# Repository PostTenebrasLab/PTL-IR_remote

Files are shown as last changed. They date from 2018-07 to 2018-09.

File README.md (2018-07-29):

# PTL IR remote

PTL IR remote is a wemos shield with sensors and actuators.

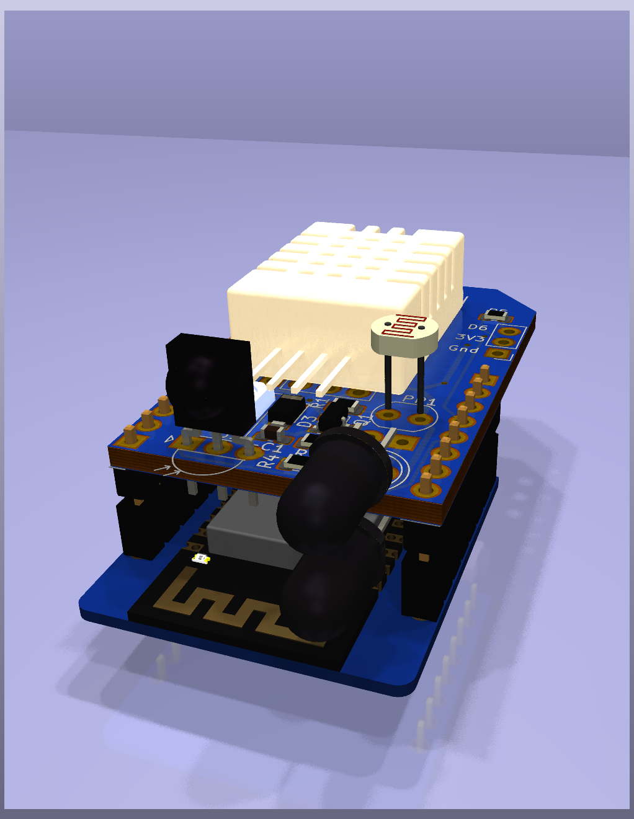
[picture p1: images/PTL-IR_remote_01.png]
Logo Title Text 1


## Sensors / Actuators

 * IR leds
 * IR receiver
 * DHT22 temperature/humidity
 * brithness (photoresistor)
 * optional ds18b20 termometer (or any OneWire perif)
 * optional bme280 temperature/humidity/pressure

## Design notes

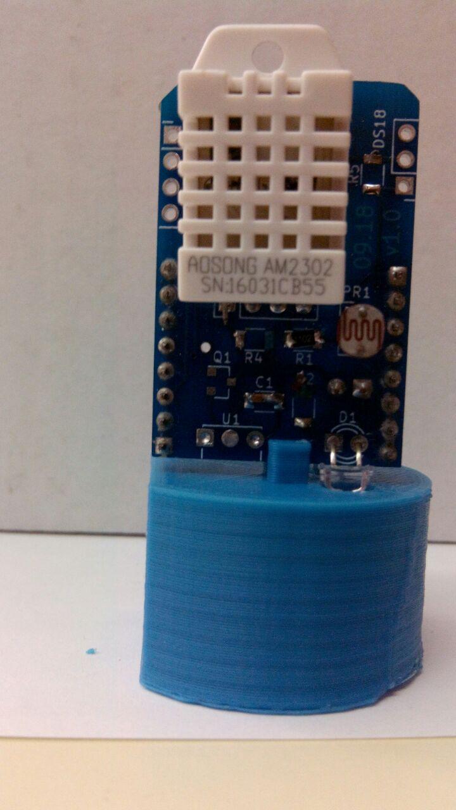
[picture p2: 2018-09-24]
presentation_workshop/pics/led_support.jpg

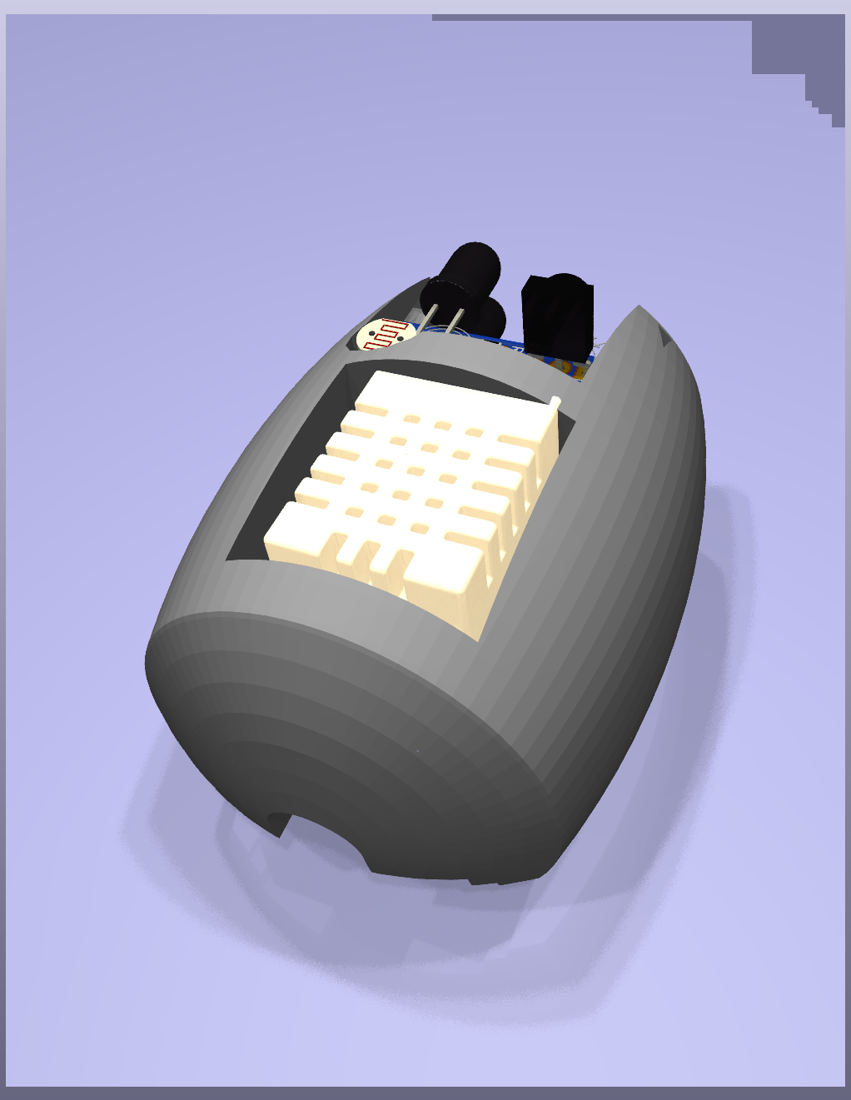
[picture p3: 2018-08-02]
presentation_workshop/images/PTL-IR_remote_case_02.png

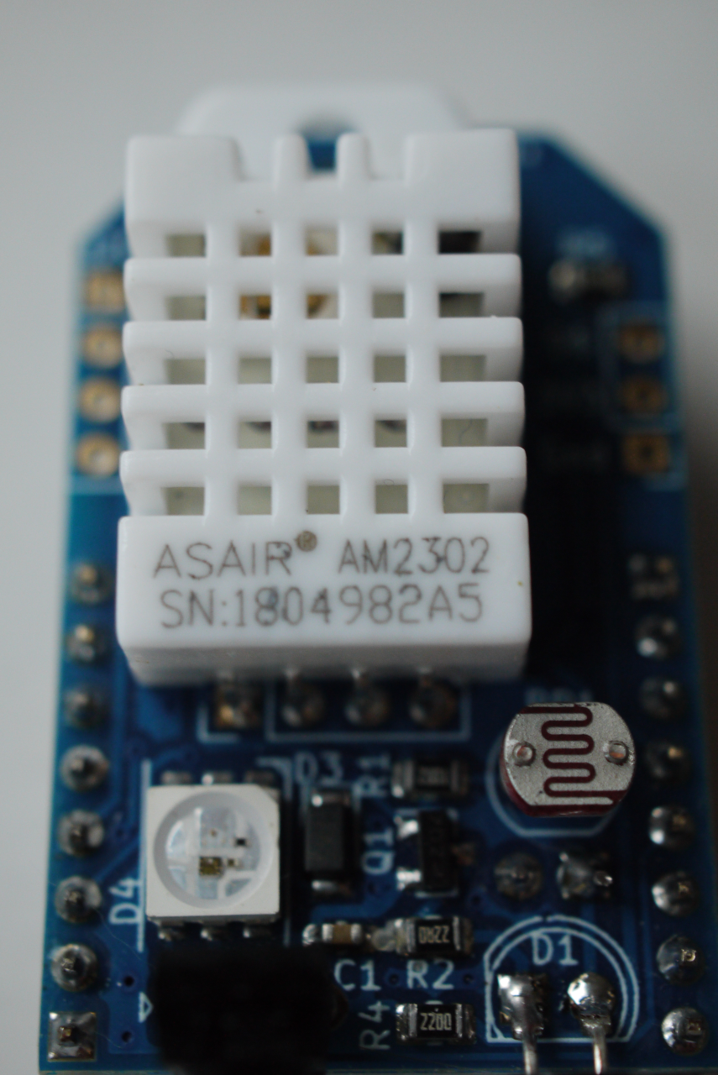
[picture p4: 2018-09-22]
presentation_workshop/pics/DHT22_1.png

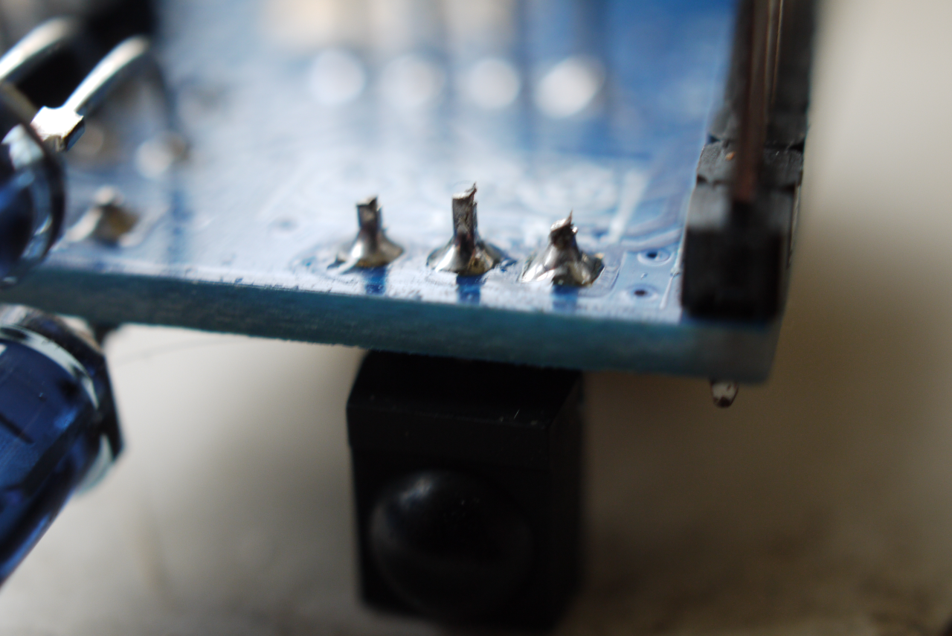
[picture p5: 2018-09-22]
presentation_workshop/pics/exemple_receiver.png

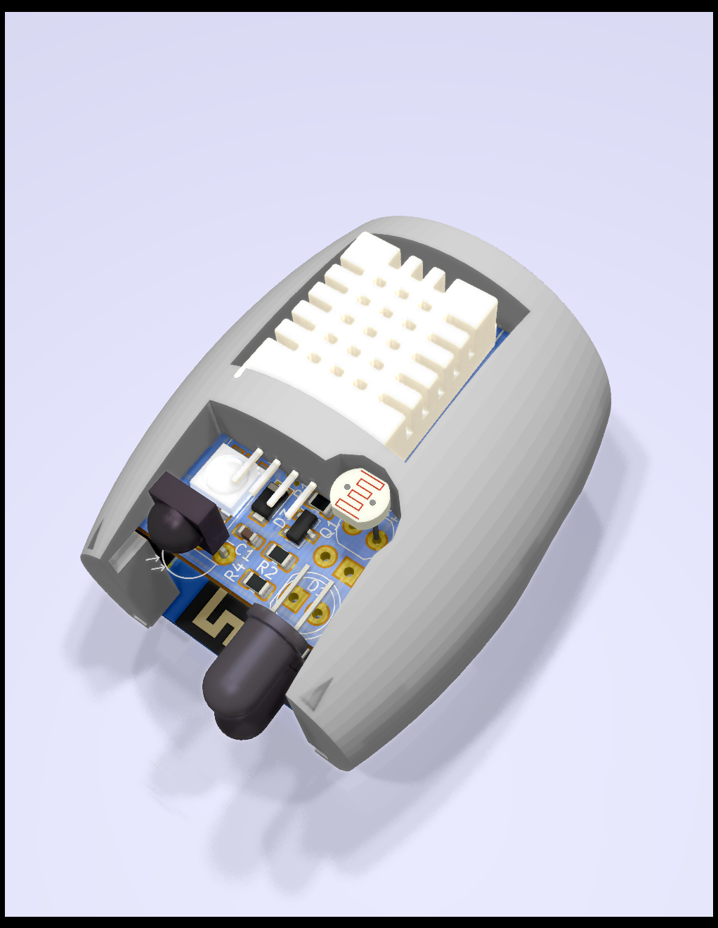
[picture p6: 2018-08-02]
presentation_workshop/images/PTL-IR_remote_case_04.png

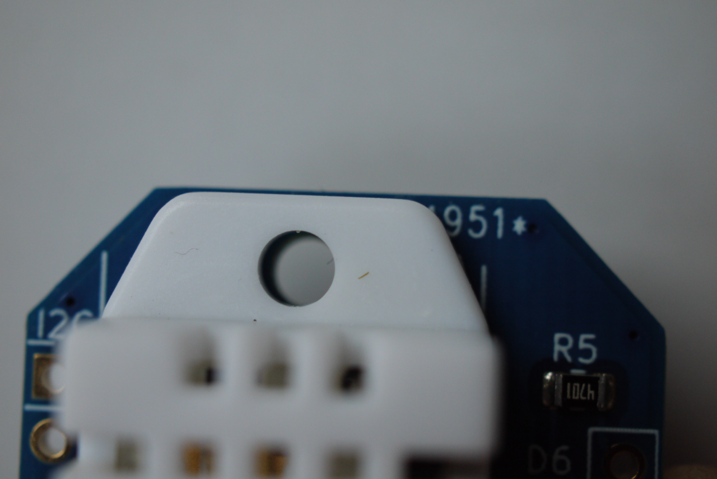
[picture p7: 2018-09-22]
presentation_workshop/pics/DHT22_2.png

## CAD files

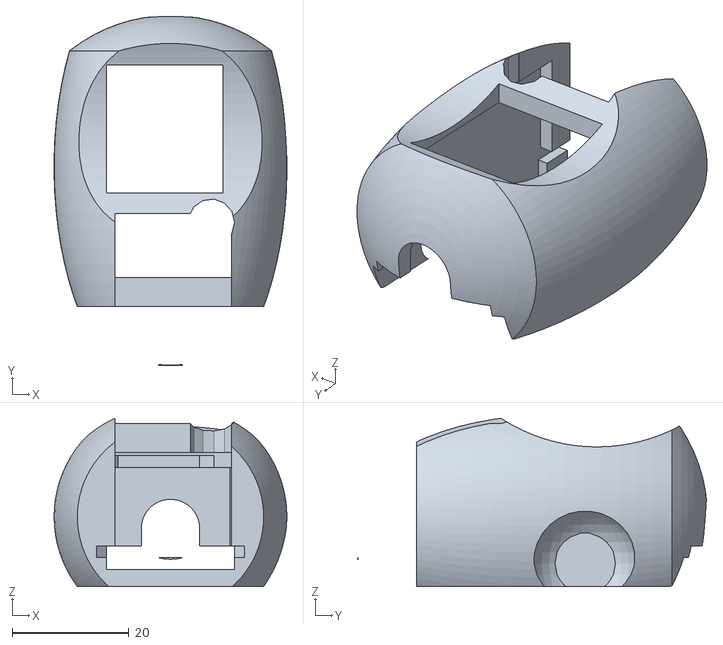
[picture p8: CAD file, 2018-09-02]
mechanical/PTL_IR_remote_case.stl
40.0 x 59.9 x 28.9

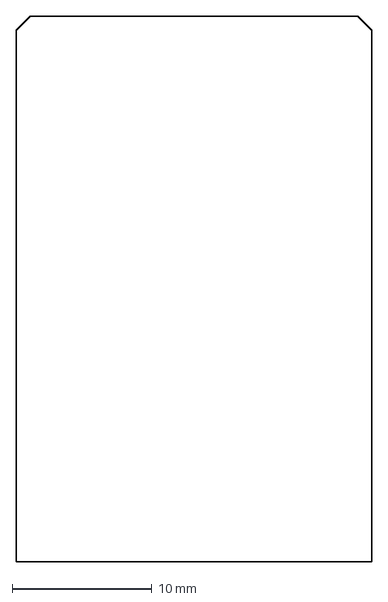
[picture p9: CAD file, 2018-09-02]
mechanical/shield_space.dxf
25.4 x 39.0 mm

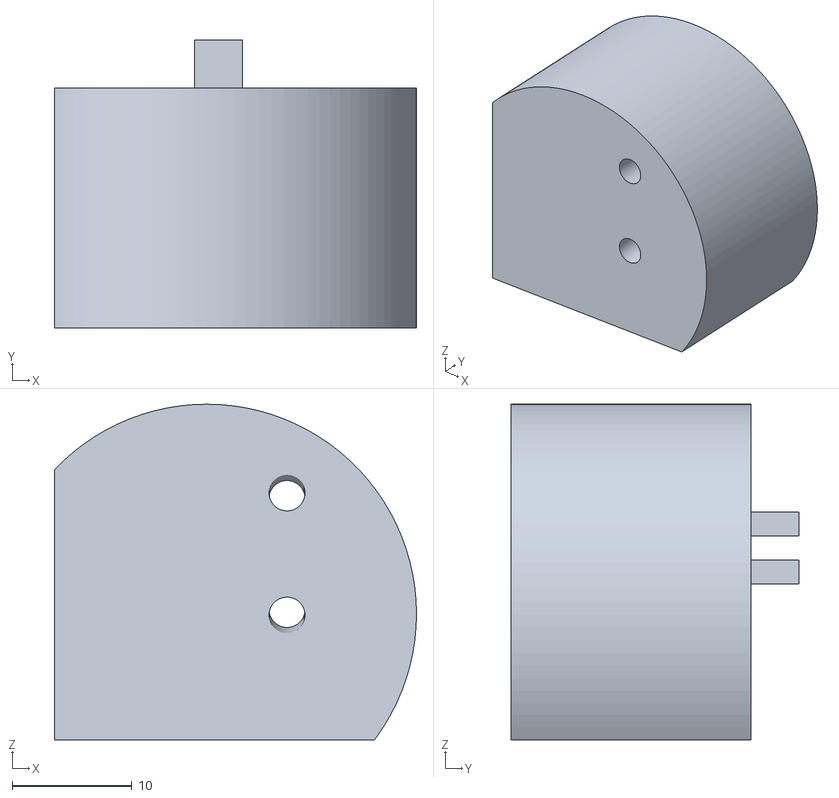
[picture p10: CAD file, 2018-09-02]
mechanical/soldering_support.stl
30.2 x 24.0 x 28.0

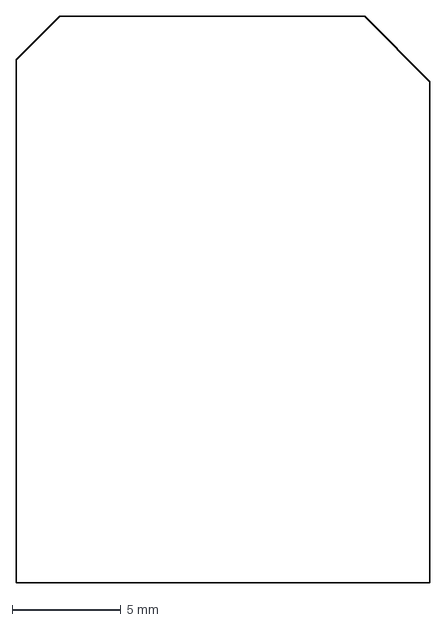
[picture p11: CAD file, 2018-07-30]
mechanical/dht.dxf
19.0 x 26.0 mm

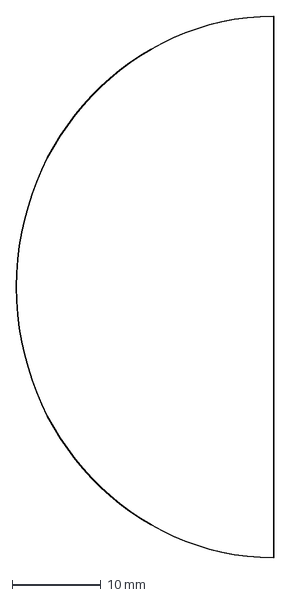
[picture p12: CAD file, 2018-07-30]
mechanical/ovoid.dxf
29.0 x 61.0 mm

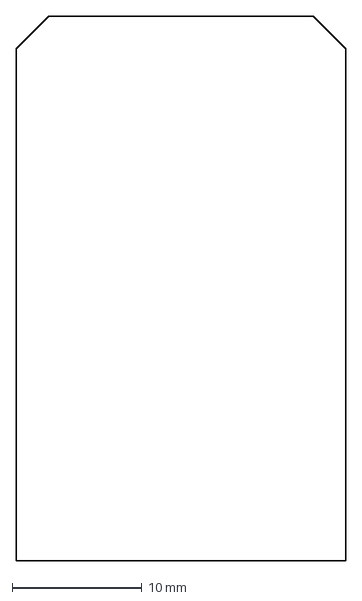
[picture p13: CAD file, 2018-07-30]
mechanical/shield.dxf
25.4 x 42.0 mm

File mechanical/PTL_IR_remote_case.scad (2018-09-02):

/* =====================================================================================
 *
 *       Filename:  sPTL_ir_remote_case.scad
 *
 *    Description:  PTL IR remote control case for LemanMake 2018 PTL workshop
 *
 *        Version:  1.0
 *        Created:  02 09 2018
 *       Revision:  none
 *       Compiler:  gcc
 *
 *         Author:  Sebastien Chassot (sinux), sinux@posttenebraslab.ch.ch
 *        Company:  Post Tenebras Lab (Geneva's Hackerspace)
 *
 * =====================================================================================
 */


case();
//esp();
//esp_clearance();

module case (){
color([0,1,0])
difference(){
    case_full();
    esp_clearance();
}
}

/**
 *    Case without clearance
 **/
module case_full () {

    difference(){
        translate([0,-16,5])
        rotate([-90,0,0])
        intersection(){
    
            rotate_extrude(convexity = 10, $fn=80)import(file = "ovoid.dxf");
    
            translate([0,0,35])
                scale([1,1,2])sphere(d=40, $fn=80);
        }
        translate([-50,-50,-27])
            cube([100,100,20]);
        
        //truncate
        translate([-20,-15,-20])
            cube([40,10,40]);
        
        translate([0, 26, 47])
        rotate([0, 90, 0])
            cylinder(d=60, h=100, center=true, $fn=100);
    }
}


/**
 *    wemos + shield
 **/
module esp () {
    
    union() {
        // wemos
        color([0,0,1])
        translate([-25.4/2,-7,-2])
            cube([25.4,35,2]);
        
        // headers
        color([0,0,0])
        translate([-25.4/2,0,0])
            cube([2.54,23,11.5]);
        color([0,0,0])
        translate([25.4/2-2.54,0,0])
            cube([2.54,23,11.5]);
        
        // shield
        color([0,0,1])
        translate([0,0,11.5])
            linear_extrude(2)import(file = "shield.dxf");
        
        // DHT
        translate([-9.5,15,7.5]){
            color([1,1,1])
            translate([-1,0,6])
                cube([19,20,7.5]);
            
            color([1,1,1])
            translate([-1,.5,6])
                linear_extrude(2)import(file = "dht.dxf");
        }
    }
}

/**
 *    wemos clearance
 **/
module esp_clearance () {
    color([1,0,0])
    union() {
         // shield
        translate([0, 0, -2])
            linear_extrude(15.5)import(file = "shield.dxf");
        
        translate([-25.4/2, -30, -2])
            cube([25.4, 60, 2]);
        
        // shield space
        translate([0, -3, 13.5])
            linear_extrude(2.5)import(file = "shield_space.dxf");
            
        // DHT
        translate([-10,14.5,13.5]){
            color([1,1,1])
            translate([-1,0,0])
                cube([20,22,14]);
            
            color([1,1,1])
            translate([-1,.5,0])
                linear_extrude(2)import(file = "dht.dxf");
        };
    
    
        // clear space
        translate([-9.5,-17,-2]) 
            cube([20,28,27]);
        
        // clip
        translate([-11,-15,-4]) 
            cube([22,70,4]);
        translate([-25.4/2,0,-7])
            cube([25.4,45,5]);
    
        // USB wire
        translate([0,47,3])
        rotate([90,0,0]) {
            cylinder(d=10, h=10, $fn=100);
            translate([0, -4, 5])
                cube([10, 8, 10],center=true);
        }

        // photoresistor
        translate([7,9.5,0])
            cylinder(d=8, h=40);
        
        
        // reset button
        translate([20,24,-3])
            sphere(d=18);
    }
}

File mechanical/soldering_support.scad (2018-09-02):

/* =====================================================================================
 *
 *       Filename:  soldering_support.scad
 *
 *    Description:  Soldering support for LemanMake 2018 PTL workshop
 *
 *        Version:  1.0
 *        Created:  02 09 2018
 *       Revision:  none
 *       Compiler:  gcc
 *
 *         Author:  Sebastien Chassot (sinux), sinux@posttenebraslab.ch.ch
 *        Company:  Post Tenebras Lab (Geneva's Hackerspace)
 *
 * =====================================================================================
 */

LEDS_ANGLE=3;

support();

module support() {
    union() {
        difference() {    
            translate([0, 0, 35/2-7])
                rotate([90, 0, 0])
                    cylinder(d=35, h=20, $fn=100);

            union() {
                translate([6.7, 1, 11.5])
                    rotate([90+LEDS_ANGLE, 0, 0]) {
                        cylinder(d1=5.7, d2=4.7, h=12, $fn=100);
                        cylinder(d=3, h=22, $fn=100);
                    };

                translate([6.7, 1, 19.5])
                    rotate([90-LEDS_ANGLE, 0, 0]) {
                        cylinder(d1=5.7, d2=4.7, h=12, $fn=100);
                        cylinder(d=3, h=22, $fn=100);
                    };

                translate([0, 0, -15])
                    cube([50, 50, 30], center=true);
                cube([26.5, 15, 4], center=true);
                
                rotate([0, 90, 0]) {
                    translate([0, 0, -27.7]) {
                        cube([50, 50, 30], center=true);
                    }
                    
                }
               // cube([26.5, 15, 4], center=true);
            }
        }

        translate([0, 0, 16])
            rotate([0, 90, 0]) {
                translate([-3, -1, -1])
                    cube([2, 5, 4]);
                translate([1, -1, -1])
                    cube([2, 5, 4]);
            }
    }
}

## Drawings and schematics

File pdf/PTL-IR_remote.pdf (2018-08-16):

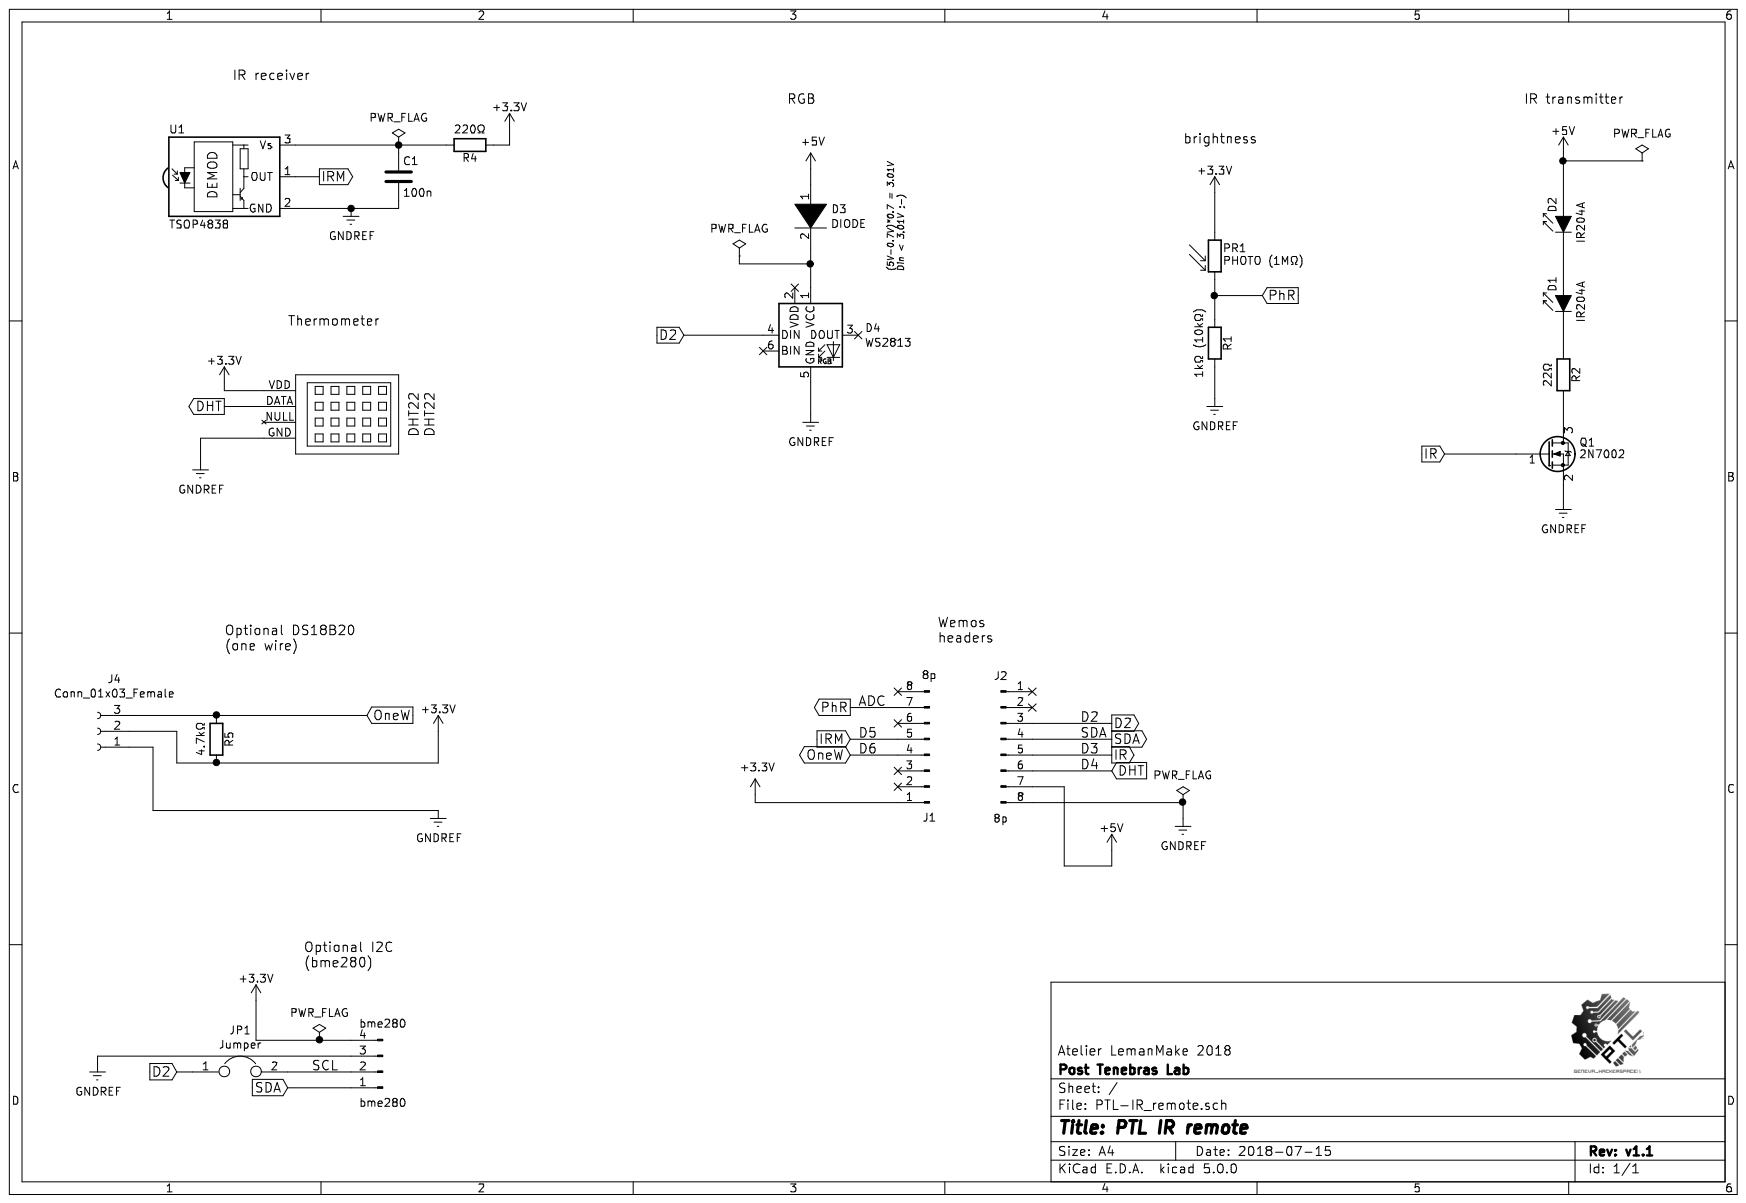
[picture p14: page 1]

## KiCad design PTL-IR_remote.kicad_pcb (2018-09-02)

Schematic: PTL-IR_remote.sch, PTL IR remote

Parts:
C1: 100n; C_0603_1608Metric_Pad1.05x0.95mm_HandSolder
D1, D2: IR204A; LED_D5.0mm_IRGrey
D3: DIODE; D_PowerDI-123
D4: WS2813; LED_WS2812_PLCC6_5.0x5.0mm_P1.6mm
DHT22: DHT22; PinHeader_1x04_P2.54mm_Vertical
J1, J2: 8p; PinHeader_1x08_P2.54mm_Vertical
J4: Conn_01x03_Female; PinHeader_1x03_P2.54mm_Vertical
JP1: Jumper; solder-jumper-2
PR1: PHOTO (1MΩ); R_LDR_4.9x4.2mm_P2.54mm_Vertical
Q1: 2N7002; SOT-23
R1: 1kΩ (10kΩ); R_0805_2012Metric
R2: 22Ω; R_0805_2012Metric
R4: 220Ω; R_0805_2012Metric
R5: 4.7kΩ; R_0805_2012Metric
U1: TSOP4838; Vishay_MINIMOLD-3Pin
bme280: bme280; PinHeader_1x04_P2.54mm_Vertical

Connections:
+3V3: DHT22.1, J1.1, J4.2, PR1.1, R4.1, R5.2, bme280.4
+5V: D2.2 (A), D3.1, J2.8
DHT: DHT22.2, J2.3, JP1.1
GNDREF: C1.2, D4.5, DHT22.4, J2.7, J4.1, Q1.2 (S), R1.2, U1.2 (GND), bme280.3
IR: J2.5, Q1.1 (G)
IRM: J1.5, U1.1 (OUT)
unnamed: C1.1, R4.2, U1.3 (Vs)
unnamed: D1.1 (K), R2.1
unnamed: D1.2 (A), D2.1 (K)
unnamed: D3.2, D4.1
unnamed: JP1.2, bme280.2
unnamed: Q1.3 (D), R2.2
OneW: J1.4, J4.3, R5.1
PhR: J1.7, PR1.2, R1.1
RGB: D4.4, J2.6
SDA: J2.4, bme280.1

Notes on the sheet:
(5V-0.7V)*0.7 = 3.01V Din < 3.01V ;-)
Optional DS18B20 (one wire)
Optional I2C (bme280)
IR receiver
Thermometer
Wemos headers
RGB
brightness
IR transmitter
SCL

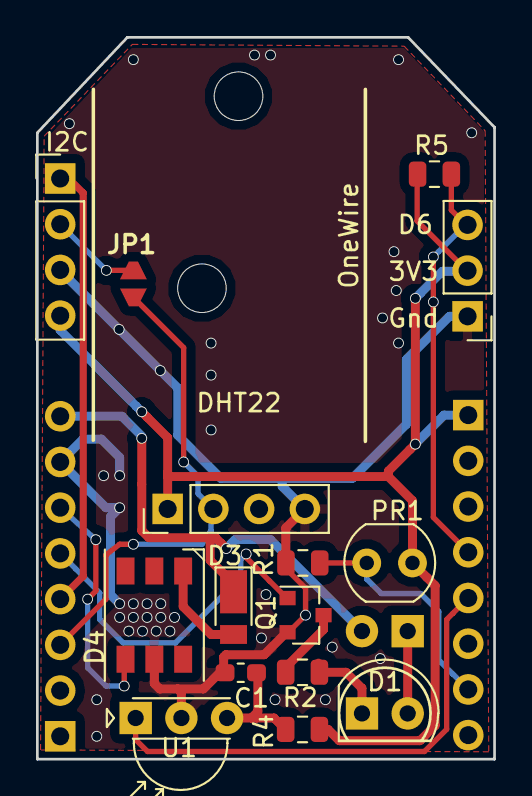
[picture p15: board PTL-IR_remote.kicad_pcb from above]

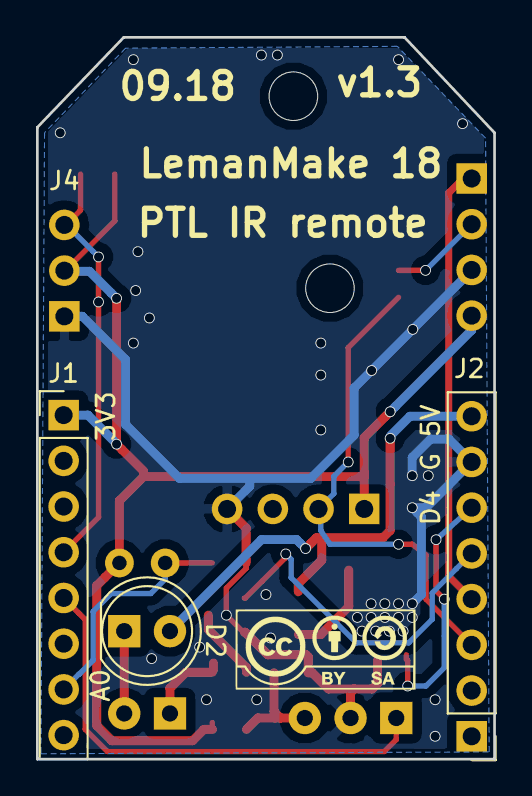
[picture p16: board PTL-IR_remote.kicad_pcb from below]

Board: 2 copper layers, 25.4 x 40.1 mm, 18 parts (3 on the bottom side), 16 nets.

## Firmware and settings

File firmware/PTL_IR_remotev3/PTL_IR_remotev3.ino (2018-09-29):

/*
  WS2812FX Webinterface.
  
  Harm Aldick - 2016
  www.aldick.org

  
  FEATURES
    * Webinterface with mode, color, speed and brightness selectors


  LICENSE

  The MIT License (MIT)

  Copyright (c) 2016  Harm Aldick 

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
  
  CHANGELOG
  2016-11-26 initial version
  2018-01-06 added custom effects list option and auto-cycle feature
  
*/

#include <WiFiManager.h>
#include <DNSServer.h>
#include <ESP8266mDNS.h>

#include <ESP8266WebServer.h>
#include <ESP8266OTA.h>
#include <ESP8266httpUpdate.h>

#include <DHTesp.h>
#include <WS2812FX.h>

#include <IRremoteESP8266.h>
#include <IRrecv.h>
#include <IRsend.h>
#include <IRutils.h>
#include <ir_Daikin.h>
#include <ir_Fujitsu.h>
#include <ir_Gree.h>
#include <ir_Haier.h>
#include <ir_Kelvinator.h>
#include <ir_Midea.h>
#include <ir_Toshiba.h>

#include "PTL_IR_remotev3.h"

extern const char index_html[];
extern const char ws2813_html[];
extern const char ir_html[];

extern const char main_js[];
extern const char ir_js[];
extern const char ws2813_js[];

#define WIFI_TIMEOUT 30000              // checks WiFi every ...ms. Reset after this time, if WiFi cannot reconnect.
#define HTTP_PORT 80

#define CAPTURE_BUFFER_SIZE 1024
#define TIMEOUT 15U  // Suits most messages, while not swallowing many repeats.
#define MIN_UNKNOWN_SIZE 12
#define DEFAULT_COLOR 0x00FF00
#define DEFAULT_BRIGHTNESS 255  // 0..255
#define DEFAULT_SPEED 1000
#define DEFAULT_MODE FX_MODE_BREATH


//#define DEBUG


unsigned long auto_last_change = 0;
unsigned long last_wifi_check_time = 0;
String modes = "";
uint8_t myModes[] = {}; // *** optionally create a custom list of effect/mode numbers
boolean auto_cycle = false;
int8_t brightness = DEFAULT_BRIGHTNESS;
uint8_t lastMode;

/*****  WIFI  *****/
WiFiManager wifiManager;
ESP8266WebServer server(HTTP_PORT);
ESP8266OTA otaUpdater;

/*****  IR  *****/
IRsend irsend = IRsend(IR_LED_PIN);
IRrecv irrecv(IR_RECV_PIN, 1024, 15u, true);
decode_results results;  // Somewhere to store the results
bool ir_lock = false;  // Primitive locking for gating the IR LED.
uint16_t * newCodeArray(const uint16_t size);
uint16_t countValuesInStr(const String str, char sep);
uint32_t sendReqCounter = 0;
// HTML arguments we will parse for IR code information.
#define argType "type"
#define argData "code"
#define argBits "bits"
#define argRepeat "repeats"

/*****  DHT and LED  *****/
DHTesp dht;
WS2812FX ws2812fx = WS2812FX(LED_COUNT, LED_PIN, NEO_GRB + NEO_KHZ800);
long timer_serial = 0;


// QUICKFIX...See https://github.com/esp8266/Arduino/issues/263
#define min(a,b) ((a)<(b)?(a):(b))
#define max(a,b) ((a)>(b)?(a):(b))

/**
 * 
 */
void wifi_setup() {
    delay(10);

    // We start by connecting to a WiFi network
    wifiManager.setTimeout(300);  // Time out after 5 mins.
    if (!wifiManager.autoConnect(WIFI_AP_NAME)) {
        Serial.print("Wifi failed to connect and hit timeout.");
        // Reboot. A.k.a. "Have you tried turning it Off and On again?"
        ESP.reset();
    }
    if (!MDNS.begin(HOSTNAME)) {
        Serial.println("Error setting up MDNS responder!");
    }
    Serial.print("WiFi connected. IP address:\t");
    Serial.println(WiFi.localIP().toString());
    Serial.print("WiFi connected. MAC address:\t");
    Serial.println(WiFi.macAddress());
}

/**
 * 
 */
bool updateOTA(){

    t_httpUpdate_return  ret = ESPhttpUpdate.update(FW_UPDATE_URL);

//    Serial.println(ESPhttpUpdate.getLastError());
    switch(ESPhttpUpdate.getLastError()) {
        case 11:
            Serial.println("OTA : Updating firmware...");
            break;
        case -11:
            Serial.println("OTA : esp unknown in PTL esp DB...");
            break;
        case -1:
            Serial.println("OTA : No server found");
            break;
        case -102:
            Serial.println("OTA : No update needed current firmware is up to date.");
            break;
        default:
           Serial.println("Unknown error");
    }
    return (ret == 11) ? true : false;    
}

void calibrateIr(int8_t* offset){

  irsend.begin();

  *offset = irsend.calibrate();

}


void irInit(){
  irsend.begin();
  irrecv.setUnknownThreshold(MIN_UNKNOWN_SIZE);
  irrecv.enableIRIn();  // Start the receiver
}


void readIr(){
   // Check if the IR code has been received.
  if (irrecv.decode(&results)) {
    
    translateIR();

    if (results.overflow)
      Serial.printf("WARNING: IR code is too big for buffer (>= %d). "
                    "This result shouldn't be trusted until this is resolved. "
                    "Edit & increase CAPTURE_BUFFER_SIZE.\n",
                    CAPTURE_BUFFER_SIZE);
#ifdef DEBUG
    Serial.print(resultToHumanReadableBasic(&results));
#endif
    yield();  // Feed the WDT (again)

  }
}

void translateIR() // takes action based on IR code received

// describing Car MP3 IR codes 

{

  switch(results.value)

  {

  case 0xFF00FF:  
    Serial.println(" On             ");
    ws2812fx.setMode(lastMode);
    ws2812fx.setBrightness(brightness);
    break;

  case 0xFF807F:  
    Serial.println(" Off            ");
    lastMode = ws2812fx.getMode();
    ws2812fx.setBrightness(0);
    break;

  case 0xFF40BF:  
    Serial.println(" Flash          ");
    (ws2812fx.getMode() == 34) ? ws2812fx.setMode(0) : ws2812fx.setMode(34);
    break;

  case 0xFF20DF:  
    Serial.println(" Strobe         ");
    (ws2812fx.getMode() == 34) ? ws2812fx.setMode(0) : ws2812fx.setMode(34);
    break;

  case 0xFFA05F:  
    Serial.println(" Fade           ");
    (ws2812fx.getMode() == 15) ? ws2812fx.setMode(0) : ws2812fx.setMode(15);
    break;

  case 0xFF609F:  
    Serial.println(" Smooth         "); 
    (ws2812fx.getMode() == 15) ? ws2812fx.setMode(0) : ws2812fx.setMode(15);
    break;

  case 0xFF10EF:  
    Serial.println(" Light Up       ");
    brightness = (brightness >= 230) ? 255 : brightness + 25;
    ws2812fx.setBrightness(brightness);
    break;

  case 0xFF906F:  
    Serial.println(" Light Down     ");
    brightness = (brightness <= 25) ? 0 : brightness - 25;
    ws2812fx.setBrightness(brightness);
    break;

  case 0xFF50AF:  
    Serial.println(" W              ");
    ws2812fx.setColor(WHITE);
    break;

  case 0xFF30CF:  
    Serial.println(" Red            "); 
    ws2812fx.setColor(RED);
    break;

  case 0xFFB04F:  
    Serial.println(" Green          "); 
    ws2812fx.setColor(GREEN);
    break;

  case 0xFF708F:  
    Serial.println(" Blue           "); 
    ws2812fx.setColor(BLUE);
    break;

  case 0xFF08F7:  
    Serial.println(" c1             "); 
    ws2812fx.setColor(ORANGE);
    break;

  case 0xFF8877:  
    Serial.println(" c2             "); 
    ws2812fx.setColor(GREEN);
    break;

  case 0xFF48B7:  
    Serial.println(" c3             "); 
    ws2812fx.setColor(BLUE);
    break;

  case 0xFF28D7:  
    Serial.println(" c4             "); 
    ws2812fx.setColor(GREEN);
    break;

  case 0xFFA857:
    Serial.println(" c5             "); 
    ws2812fx.setColor(CYAN);
    break;

  case 0xFF6897:  
    Serial.println(" c6             "); 
    ws2812fx.setColor(PINK);
    break;

  case 0xFF18E7:  
    Serial.println(" c7             "); 
    ws2812fx.setColor(YELLOW);
    break;

  case 0xFF9867:  
    Serial.println(" c8             "); 
    ws2812fx.setColor(GREEN);
    break;

  case 0xFF58A7:  
    Serial.println(" c9             "); 
    ws2812fx.setColor(MAGENTA);
    break;

  case 0xFF52AD:  
    Serial.println(" 9              "); 
    ws2812fx.setColor(PURPLE);
    break;

  default: 
    Serial.println(" other button   ");

  }

  delay(500);


} //END translateIR




// needed by http server (display counter)
uint32_t getReqCounter(){
  return sendReqCounter;
}

// Arduino framework doesn't support strtoull(), so make our own one.
uint64_t getUInt64fromHex(char const *str) {
    uint64_t result = 0;
    uint16_t offset = 0;
    // Skip any leading '0x' or '0X' prefix.
    if (str[0] == '0' && (str[1] == 'x' || str[1] == 'X'))
       offset = 2;
    for (; isxdigit((unsigned char)str[offset]); offset++) {
        char c = str[offset];
        result *= 16;
        if (isdigit(c)) /* '0' .. '9' */
          result += c - '0';
        else if (isupper(c)) /* 'A' .. 'F' */
          result += c - 'A' + 10;
        else /* 'a' .. 'f'*/
          result += c - 'a' + 10;
    }
    return result;
}

// Parse an IRremote Raw Hex String/code and send it.
// Args:
//   str: A comma-separated String containing the freq and raw IR data.
//        e.g. "38000,9000,4500,600,1450,600,900,650,1500,..."
//        Requires at least two comma-separated values.
//        First value is the transmission frequency in Hz or kHz.
void parseStringAndSendRaw(const String str) {
  uint16_t count;
  uint16_t freq = 38000;  // Default to 38kHz.
  uint16_t *raw_array;

  // Find out how many items there are in the string.
  count = countValuesInStr(str, ',');

  // We expect the frequency as the first comma separated value, so we need at
  // least two values. If not, bail out.
  if (count < 2) return;
  count--;  // We don't count the frequency value as part of the raw array.

  // Now we know how many there are, allocate the memory to store them all.
  raw_array = newCodeArray(count);

  // Grab the first value from the string, as it is the frequency.
  int16_t index = str.indexOf(',', 0);
  freq = str.substring(0, index).toInt();
  uint16_t start_from = index + 1;
  // Rest of the string are values for the raw array.
  // Now convert the strings to integers and place them in raw_array.
  count = 0;
  do {
    index = str.indexOf(',', start_from);
    raw_array[count] = str.substring(start_from, index).toInt();
    start_from = index + 1;
    count++;
  } while (index != -1);

  irsend.sendRaw(raw_array, count, freq);  // All done. Send it.
  free(raw_array);  // Free up the memory allocated.
}


// Dynamically allocate an array of uint16_t's.
// Args:
//   size:  Nr. of uint16_t's need to be in the new array.
// Returns:
//   A Ptr to the new array. Restarts the ESP8266 if it fails.
uint16_t * newCodeArray(const uint16_t size) {
  uint16_t *result;

  result = reinterpret_cast<uint16_t*>(malloc(size * sizeof(uint16_t)));
  // Check we malloc'ed successfully.
  if (result == NULL) {  // malloc failed, so give up.
    Serial.printf("\nCan't allocate %d bytes. (%d bytes free)\n",
                  size * sizeof(uint16_t), ESP.getFreeHeap());
    Serial.println("Giving up & forcing a reboot.");
    ESP.restart();  // Reboot.
    delay(500);  // Wait for the restart to happen.
    return result;  // Should never get here, but just in case.
  }
  return result;
}


// Count how many values are in the String.
// Args:
//   str:  String containing the values.
//   sep:  Character that separates the values.
// Returns:
//   The number of values found in the String.
uint16_t countValuesInStr(const String str, char sep) {
  int16_t index = -1;
  uint16_t count = 1;
  do {
    index = str.indexOf(sep, index + 1);
    count++;
  } while (index != -1);
  return count;
}


// Display the human readable state of an A/C message if we can.
void dumpACInfo(decode_results *results) {
  String description = "";
#if DECODE_DAIKIN
  if (results->decode_type == DAIKIN) {
    IRDaikinESP ac(0);
    ac.setRaw(results->state);
    description = ac.toString();
  }
#endif  // DECODE_DAIKIN
#if DECODE_FUJITSU_AC
  if (results->decode_type == FUJITSU_AC) {
    IRFujitsuAC ac(0);
    ac.setRaw(results->state, results->bits / 8);
    description = ac.toString();
  }
#endif  // DECODE_FUJITSU_AC
#if DECODE_KELVINATOR
  if (results->decode_type == KELVINATOR) {
    IRKelvinatorAC ac(0);
    ac.setRaw(results->state);
    description = ac.toString();
  }
#endif  // DECODE_KELVINATOR
#if DECODE_TOSHIBA_AC
  if (results->decode_type == TOSHIBA_AC) {
    IRToshibaAC ac(0);
    ac.setRaw(results->state);
    description = ac.toString();
  }
#endif  // DECODE_TOSHIBA_AC
#if DECODE_GREE
  if (results->decode_type == GREE) {
    IRGreeAC ac(0);
    ac.setRaw(results->state);
    description = ac.toString();
  }
#endif  // DECODE_GREE
#if DECODE_MIDEA
  if (results->decode_type == MIDEA) {
    IRMideaAC ac(0);
    ac.setRaw(results->value);  // Midea uses value instead of state.
    description = ac.toString();
  }
#endif  // DECODE_MIDEA
#if DECODE_HAIER_AC
  if (results->decode_type == HAIER_AC) {
    IRHaierAC ac(0);
    ac.setRaw(results->state);
    description = ac.toString();
  }
#endif  // DECODE_HAIER_AC
  // If we got a human-readable description of the message, display it.
  if (description != "")  Serial.println("Mesg Desc.: " + description);
}

void setup(){
  Serial.begin(115200);
  Serial.println();
  Serial.println();
  Serial.println("Starting...");

  modes.reserve(5000);
  modes_setup();

  Serial.println("WS2812FX setup");
  ws2812fx.init();
  ws2812fx.setMode(DEFAULT_MODE);
  ws2812fx.setColor(DEFAULT_COLOR);
  ws2812fx.setSpeed(DEFAULT_SPEED);
  ws2812fx.setBrightness(DEFAULT_BRIGHTNESS);
  ws2812fx.start();

  Serial.println("Wifi setup");
  wifi_setup();

  Serial.println("web OTA updater");
  updateOTA();
  //set web UI
  otaUpdater.setUpdaterUi("Title","LemanMake PTL workshop OTA updater","Build : 1.3","Branch : master","Device info : LemanMake workshop","footer");
  otaUpdater.setup(&server);
  
  Serial.println("DHT22 setup");
  dht.setup(DHT_PIN, DHTesp::DHT22);
 
  Serial.println("HTTP server setup");
  server.on("/", srv_handle_index_html);
  server.on("/led", srv_handle_ws2813_html);
  server.on("/ir", srv_handle_ir_html);
  server.on("/ir_rest", srv_handle_ir_rest);
  server.on("/temp", srv_handle_temp);
  server.on("/hum", srv_handle_hum);
  server.on("/lum", srv_handle_lum);
  server.on("/main.js", srv_handle_main_js);
  server.on("/ir.js", srv_handle_ir_js);
  server.on("/ws2813.js", srv_handle_ws2813_js);
  server.on("/modes", srv_handle_modes);
  server.on("/set", srv_handle_set);
  server.onNotFound(srv_handle_not_found);
  server.begin();
  Serial.println("HTTP server started.");

  Serial.println("IR server setup");
  irInit();

  Serial.println("ready!");
}


void loop() {
  unsigned long now = millis();

  server.handleClient();
  ws2812fx.service();
  readIr();

  if(millis() > timer_serial) {

    Serial.print("Temp :");
    Serial.println(getTemperature());

    Serial.print("Hum :");
        Serial.println(getHumidity());

    Serial.print("Lum :");
    Serial.println(getLuminosity());

#ifdef DEBUG
    irsend.sendNEC(0xFFB04F, 32, 5);
#endif

    timer_serial = millis() + 2000;
  }

  if(auto_cycle && (now - auto_last_change > 10000)) { // cycle effect mode every 10 seconds
    uint8_t next_mode = (ws2812fx.getMode() + 1) % ws2812fx.getModeCount();
    if(sizeof(myModes) > 0) { // if custom list of modes exists
      for(uint8_t i=0; i < sizeof(myModes); i++) {
        if(myModes[i] == ws2812fx.getMode()) {
          next_mode = ((i + 1) < sizeof(myModes)) ? myModes[i + 1] : myModes[0];
          break;
        }
      }
    }
    ws2812fx.setMode(next_mode);
    Serial.print("mode is "); Serial.println(ws2812fx.getModeName(ws2812fx.getMode()));
    auto_last_change = now;
  }
}


/*
 * Build <li> string for all modes.
 */
void modes_setup() {
  modes = "";
  uint8_t num_modes = sizeof(myModes) > 0 ? sizeof(myModes) : ws2812fx.getModeCount();
  for(uint8_t i=0; i < num_modes; i++) {
    uint8_t m = sizeof(myModes) > 0 ? myModes[i] : i;
    modes += "<li><a href='#' class='m' id='";
    modes += m;
    modes += "'>";
    modes += ws2812fx.getModeName(m);
    modes += "</a></li>";
  }
}

/* #####################################################
#  Webserver Functions
##################################################### */

void srv_handle_not_found() {
  server.send(404, "text/plain", "File Not Found");
}

void srv_handle_index_html() {
  server.send_P(200,"text/html", index_html);
}

void srv_handle_ws2813_html() {
  server.send_P(200,"text/html", ws2813_html);
}

void srv_handle_ir_html() {
  server.send_P(200,"text/html", ir_html);
}

// Parse the URL args to find the IR code.
void srv_handle_ir_rest() {
    uint64_t data = 0;
    String data_str = "";
  
    for (uint16_t i = 0; i < server.args(); i++) {
        if (server.argName(i) == argData) {
            data = getUInt64fromHex(server.arg(i).c_str());
            data_str = server.arg(i);
        }
    }
  
    Serial.println("New code received via HTTP");
    parseStringAndSendRaw(data_str.c_str());
    srv_handle_index_html();
}

void srv_handle_main_js() {
  server.send_P(200,"application/javascript", main_js);
}

void srv_handle_ws2813_js() {
  server.send_P(200,"application/javascript", ws2813_js);
}

void srv_handle_ir_js() {
  server.send_P(200,"application/javascript", ir_js);
}

void srv_handle_modes() {
  server.send(200,"text/plain", modes);
}

void srv_handle_set() {
  for (uint8_t i=0; i < server.args(); i++){
    if(server.argName(i) == "c") {
      uint32_t tmp = (uint32_t) strtol(&server.arg(i)[0], NULL, 16);
      if(tmp >= 0x000000 && tmp <= 0xFFFFFF) {
        ws2812fx.setColor(tmp);
      }
    }

    if(server.argName(i) == "m") {
      uint8_t tmp = (uint8_t) strtol(&server.arg(i)[0], NULL, 10);
      ws2812fx.setMode(tmp % ws2812fx.getModeCount());
      Serial.print("mode is "); Serial.println(ws2812fx.getModeName(ws2812fx.getMode()));
    }

    if(server.argName(i) == "b") {
      if(server.arg(i)[0] == '-') {
        ws2812fx.setBrightness(ws2812fx.getBrightness() * 0.8);
      } else if(server.arg(i)[0] == ' ') {
        ws2812fx.setBrightness(min(max(ws2812fx.getBrightness(), 5) * 1.2, 255));
      } else { // set brightness directly
        uint8_t tmp = (uint8_t) strtol(&server.arg(i)[0], NULL, 10);
        ws2812fx.setBrightness(tmp);
      }
      Serial.print("brightness is "); Serial.println(ws2812fx.getBrightness());
    }

    if(server.argName(i) == "s") {
      if(server.arg(i)[0] == '-') {
        ws2812fx.setSpeed(ws2812fx.getSpeed() * 0.8);
      } else {
        ws2812fx.setSpeed(max(ws2812fx.getSpeed(), 5) * 1.2);
      }
      Serial.print("speed is "); Serial.println(ws2812fx.getSpeed());
    }

    if(server.argName(i) == "a") {
      if(server.arg(i)[0] == '-') {
        auto_cycle = false;
      } else {
        auto_cycle = true;
        auto_last_change = 0;
      }
    }
  }
  server.send(200, "text/plain", "OK");
}

float getTemperature() {
  return dht.getTemperature();
}

void srv_handle_temp() {
  char temp[32];
  sprintf(temp, "Temperature : %.2f °C", getTemperature());
  server.send(200, "text/plain", temp);
}

float getHumidity() {
  return dht.getHumidity();
}

void srv_handle_hum() {
  char temp[32];
  sprintf(temp, "Humidity : %.2f %%", getHumidity());
  server.send(200, "text/plain", temp);
}

int getLuminosity() {
  return map(analogRead(ANALOG_PIN), 0, 1023, 0, 100);
}


void srv_handle_lum() {
  char temp[32];
  sprintf(temp, "Luminosity : %d %%", (int)round(getHumidity()));
  server.send(200, "text/plain", temp);
}

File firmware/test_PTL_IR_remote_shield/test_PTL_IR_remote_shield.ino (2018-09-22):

/*
 * =====================================================================================
 *
 *       Filename:  test_PTL_IR_remote_shield.ino
 *
 *    Description:  PTL_ir_remote running on Wemos (esp8266 D1)
 *                  esp8266 IR remote control with web server and MQTT (reder/writer)
 *
 *        Version:  1.0
 *        Created:  04/07/2018 11:12:31
 *       Revision:  none
 *       Compiler:  gcc-avr
 *
 *         Author:  Sebastien Chassot (sinux), seba.ptl@sinux.net
 *        Company:  Post Tenebras Lab (Geneva's Hackerspace)
 *
 * =====================================================================================
 */

#include "test_PTL_IR_remote_shield.h"

#define TEST_WIFI
#ifdef TEST_WIFI
#include <DNSServer.h>
#include <WiFiManager.h>
#include <ESP8266mDNS.h>

WiFiManager wifiManager;
#endif


/****** MQTT Debug *********/
#define MQTT
#ifdef MQTT

#include <PubSubClient.h>  // v2.6.0
WiFiClient espClient;

// Callback function, when the gateway receive an MQTT value on the topics
// subscribed this function is called
void callback(char* topic, byte* payload, unsigned int length) {
  // In order to republish this payload, a copy must be made
  // as the orignal payload buffer will be overwritten whilst
  // constructing the PUBLISH packet.
  // Allocate the correct amount of memory for the payload copy
  byte* payload_copy = reinterpret_cast<byte*>(malloc(length + 1));
  // Copy the payload to the new buffer
  memcpy(payload_copy, payload, length);

  // Conversion to a printable string
  payload_copy[length] = '\0';
  String callback_string = String(reinterpret_cast<char*>(payload_copy));
  String topic_name = String(reinterpret_cast<char*>(topic));

  // launch the function to treat received data
  //receivingMQTT(topic_name, callback_string);

  // Free the memory
  free(payload_copy);
}
PubSubClient mqtt_client(MQTT_SERVER, MQTT_PORT, callback, espClient);

String mqtt_clientid = ESPID;
uint32_t lastReconnectAttempt = 0;  // MQTT last attempt reconnection number
bool boot = true;
const char* mqtt_user = "";
const char* mqtt_password = "";
#endif   // 


/****** OTA firmware update *********/
#define OTA
#ifdef OTA
#include <ESP8266httpUpdate.h>

bool otaUpdate = true;
#endif

#define TEST_PERIOD 5000

/****** DHT22 thermo+hum *********/
#include "DHTesp.h"

#define TEST_DHT
#define DHT_PIN 5

DHTesp dht;
long timer_dht = 0;

/****** photoresistor *********/
#define TEST_PHOTORES
#define ANALOG_PIN  A0
long timer_photores = 0;


/****** IR *********/
#include <IRremoteESP8266.h>
#include <IRrecv.h>
#include <IRsend.h>
#include <IRutils.h>
#include <IRremoteESP8266.h>
#include <IRrecv.h>
#include <IRsend.h>
#include <IRutils.h>
#include <ir_Daikin.h>
#include <ir_Fujitsu.h>
#include <ir_Gree.h>
#include <ir_Haier.h>
#include <ir_Kelvinator.h>
#include <ir_Midea.h>
#include <ir_Toshiba.h>

#define TEST_IR
#define IR_LED 0
#define RECV_PIN 14

IRsend irsend = IRsend(IR_LED);
IRrecv irrecv(RECV_PIN, 1024, 15U, true);

decode_results results;  // Somewhere to store the results
void dumpACInfo(decode_results *results);
long timer_ir = 0;


/****** led WS2813b *********/
#include <WS2812FX.h>

#define TEST_LED
#define LED_PIN 2
#define LED_COUNT 20

#define DEFAULT_COLOR 0xFF5900
#define DEFAULT_BRIGHTNESS 255
#define DEFAULT_SPEED 1000
#define DEFAULT_MODE FX_MODE_STATIC


WS2812FX ws2812fx = WS2812FX(LED_COUNT, LED_PIN, NEO_GRB + NEO_KHZ800);
long timer_led = 0;

/****** BME280 shield *********/
#include <Adafruit_Sensor.h>
#include <Adafruit_BME280.h>
#define TEST_BME280
#define LED_PIN 2


void setup() {

  Serial.begin(115200);
  Serial.println();
  Serial.println();
  Serial.println("Starting...");


#ifdef TEST_WIFI
  setup_wifi();
#endif


/****** DHT22 thermo+hum *********/
  Serial.println("Status\tHumidity (%)\tTemperature (C)\t(F)\tHeatIndex (C)\t(F)");
  dht.setup(DHT_PIN, DHTesp::DHT22); // Connect DHT sensor to GPIO 17

#ifdef TEST_IR
  irrecv.setUnknownThreshold(12);
  irrecv.enableIRIn();  // Start the receiver
#endif

/****** led WS2813b *********/
  Serial.println("WS2812FX setup");
  ws2812fx.init();
  ws2812fx.setMode(DEFAULT_MODE);
  ws2812fx.setColor(DEFAULT_COLOR);
  ws2812fx.setSpeed(DEFAULT_SPEED);
  ws2812fx.setBrightness(DEFAULT_BRIGHTNESS);
  ws2812fx.start();
}

#ifdef TEST_WIFI
/**
 * 
 */
void setup_wifi() {
    delay(10);

    // We start by connecting to a WiFi network
    wifiManager.setTimeout(300);  // Time out after 5 mins.
    if (!wifiManager.autoConnect(WIFI_AP_NAME)) {
        Serial.print("Wifi failed to connect and hit timeout.");
        // Reboot. A.k.a. "Have you tried turning it Off and On again?"
        ESP.reset();
    }
    if (!MDNS.begin(HOSTNAME)) {
        Serial.println("Error setting up MDNS responder!");
    }
    Serial.print("WiFi connected. IP address:\t");
    Serial.println(WiFi.localIP().toString());
    Serial.print("WiFi connected. MAC address:\t");
    Serial.println(WiFi.macAddress());
}
#endif  //TEST_WIFI


#ifdef MQTT

bool reconnect() {
  // Loop a few times or until we're reconnected
  uint16_t tries = 1;
  while (!mqtt_client.connected() && tries <= 3) {
    int connected = false;
    // Attempt to connect
    Serial.println("Attempting MQTT connection to " MQTT_SERVER ":" + String(MQTT_PORT) +"... ");
    if (mqtt_user && mqtt_password)
      connected = mqtt_client.connect(mqtt_clientid.c_str(), mqtt_user,
                                      mqtt_password);
    else
      connected = mqtt_client.connect(mqtt_clientid.c_str());
    if (connected) {
    // Once connected, publish an announcement...
      mqtt_client.publish(MQTTnamespace, "Connected");
      Serial.println("connected.");
      // Subscribing to topic(s)
//      subscribing(MQTTcommand);
    } else {
      Serial.println("failed, rc=" + String(mqtt_client.state()) +" Try again in a bit.");
      // Wait for a bit before retrying
      delay(tries << 7);  // Linear increasing back-off (x128)
    }
    tries++;
  }
  return mqtt_client.connected();
}


void mqttClient(){
  // MQTT client connection management
  if (!mqtt_client.connected()) {
    uint32_t now = millis();
    // Reconnect if it's longer than MQTT_RECONNECT_TIME since we last tried.
    if (now - lastReconnectAttempt > MQTT_RECONNECT_TIME) {
      lastReconnectAttempt = now;
      Serial.println("client mqtt not connected, trying to connect");
      // Attempt to reconnect
      if (reconnect()) {
        lastReconnectAttempt = 0;
        if (boot) {
          mqtt_client.publish(MQTTnamespace, "IR Server just booted");
          boot = false;
        } else {
          mqtt_client.publish(MQTTnamespace, "IR Server just (re)connected to MQTT");
        }
      }
    }
  } else {
    // MQTT loop
    mqtt_client.loop();
  }
}

#endif //MQTT


#ifdef OTA
/**
 * 
 */
bool updateOTA(){

    t_httpUpdate_return  ret = ESPhttpUpdate.update(FW_UPDATE_URL);
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

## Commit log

2018-07-26 add correction notes on schema
    [PTL-IR_remote.sch]
2018-07-26 anotate schema modifs
    [PTL-IR_remote.sch]
2018-07-28 fix pcb v1.0 (and update to kicad v5)
    [PTL-IR_remote.kicad_pcb, PTL-IR_remote.sch]
2018-07-28 split schema
    [PTL-IR_remote.kicad_pcb, PTL-IR_remote.sch]
2018-07-28 update gerber files
    [PTL-IR_remote-B.Cu.gbr, PTL-IR_remote-B.Mask.gbr, PTL-IR_remote-B.SilkS.gbr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]
2018-07-28 minor changes
    [PTL-IR_remote.kicad_pcb, PTL-IR_remote.sch]
2018-07-28 remove unused dir
    [PTL-IR_remote-B.Cu.GBL, PTL-IR_remote-B.Mask.GBS, PTL-IR_remote-B.SilkS.GBO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]
2018-07-28 update plot for v1.1-pre
    [PTL-IR_remote-B.Cu.gbl, PTL-IR_remote-B.Cu.gbr, PTL-IR_remote-B.Mask.gbr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]
2018-07-29 change diode footprint and reroute
    [PTL-IR_remote-B.Cu.gbl, PTL-IR_remote-B.Mask.gbs, PTL-IR_remote-B.SilkS.gbo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]
2018-07-29 add 3d componants and replot
    [PTL-IR_remote-B.Cu.gbl, PTL-IR_remote-B.Mask.gbs, PTL-IR_remote-B.SilkS.gbo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]
2018-07-30 add openscad wemos case (.stl)
    [PTL_IR_remote_case.scad, PTL_IR_remote_case.stl, dht.dxf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]
2018-07-30 change led pin (D2), add jumper (bme280)
    [PTL-IR_remote-B.Cu.gbl, PTL-IR_remote-B.Mask.gbs, PTL-IR_remote-B.SilkS.gbo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]
2018-08-02 replace OneWIre pads by 2.54 header
    [PTL-IR_remote-B.Cu.gbl, PTL-IR_remote-B.Mask.gbs, PTL-IR_remote-B.SilkS.gbo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]
2018-08-16 Moved to Kicad5 Fixed swap of 5V and GND PCB is now V1.2
    [PTL-IR_remote-B.Cu.gbl, PTL-IR_remote-B.Mask.gbs, PTL-IR_remote-B.SilkS.gbo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]
2018-09-02 Fixed missing mounting holes and PTL and CC logo. Added a few missing files...
    [PTL-IR_remote-F.Paste.gtp, PTL-IR_remote.drl]
2018-09-02 add soldering support and update case (3dprinting)
    [PTL_IR_remote_case.scad, PTL_IR_remote_case.stl, shield_space.dxf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]
2018-09-02 forgot to add some modified files
    [PTL-IR_remote.kicad_pcb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]
2018-09-09 refactor serial test printout
2018-09-23 add index.html,/ir,/led pages
2018-09-26 add change IR led color
2018-09-27 add remote to led functions
